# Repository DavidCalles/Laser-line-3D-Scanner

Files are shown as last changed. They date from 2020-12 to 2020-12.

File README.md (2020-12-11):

# Laser-Line 3D Scanner
By David Calles.

# Description
This repository contains all the code, models, image sets, and diagrams for an implementation of a 3D scanner at a prototype level. Consisting of a code for the computer-end and a code for the raspberrypi-end. 
Each step must be performed individually by running each code with its corresponding pre-requisites and using the ourputs of the block before.

# Requirements
The package requirements to run the algorithms are listed in the requirements.txt file. And can be install using:

    pip3 install -r requirements.txt
 or, if one has Anaconda installed:
 
    conda install --file requirements.txt

# Software blocks diagram
The following image illustrates the main stages of the software in the repository. 
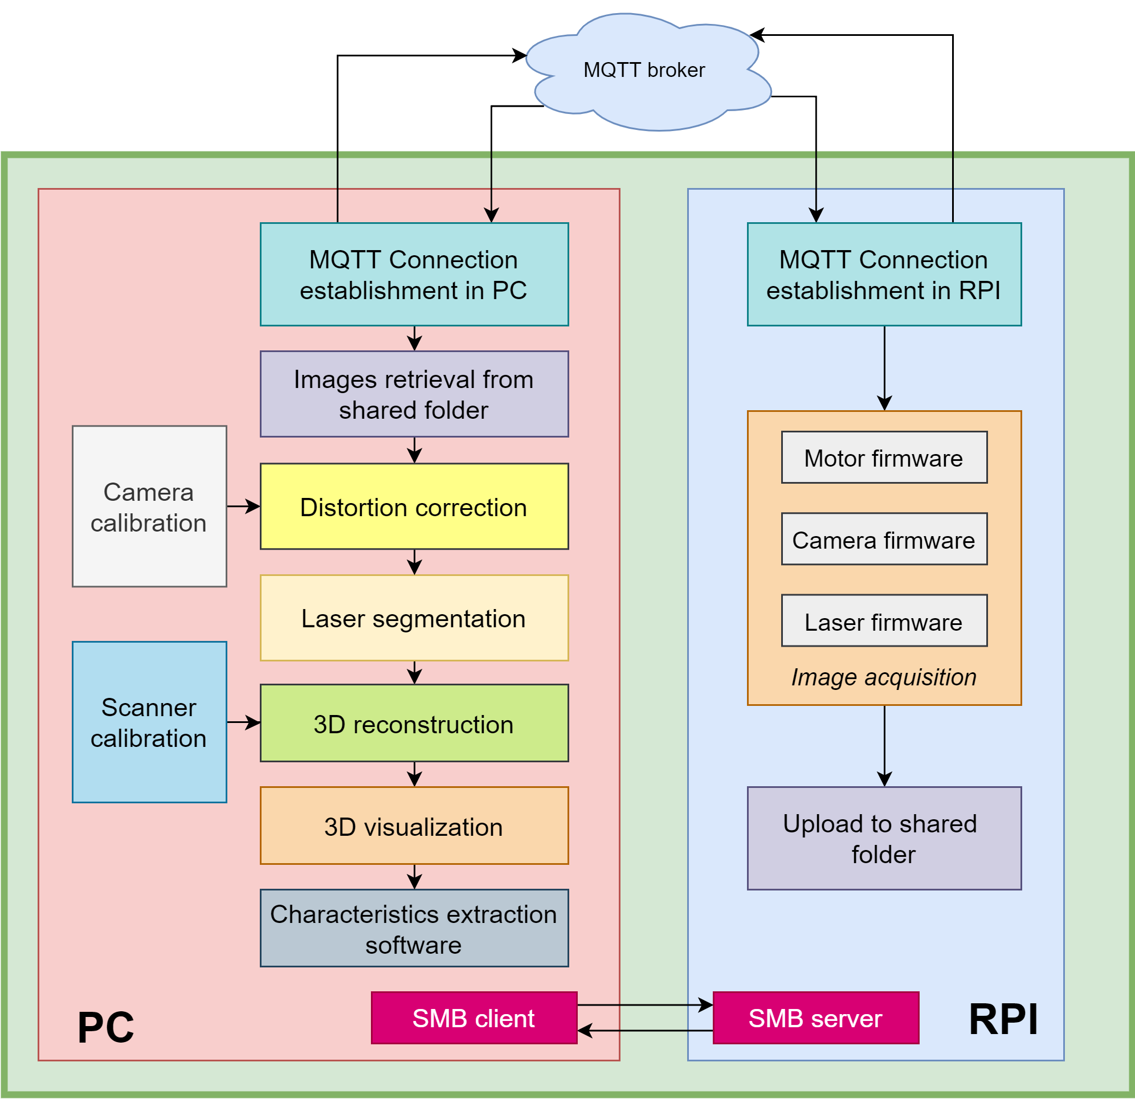
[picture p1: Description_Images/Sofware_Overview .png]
Blocks_Diagram


To get more information on each block as well as the fundamentals and theory of each algorithm, you are encourage to read the book located in the "Official_Documents" folder. In this document, the results using this scanner as well as a comparison with a time-of-flight sensor, and a plenoptic camera results is exposed.

# Files and folders
## Image sets
All the image sets needed to perform the different calibrations are included:

 - Camera calibration image set (100 images)
 - Scanner calibration image set (212 images = 106 image pairs)
 - Center calibration image set (4 images)

The same way, two different image sets for reconstructing its point clouds are included:

 - Volleyball ball (1500 images = 750 image pairs) 
 - Chili plant (1500 images = 750 image pairs)

## Sample point clouds

Two ascci XYZ files of the reconstructed point clouds are also shared in the "Sample point clouds" folder.

## 3D-print models
All the models for printing the car, the platform segments, the motor adapters, and the of the scanner are shared as STL files. More information can be found in the final book pdf file. 

## PCB files
All the gerber and drill files of the PCB for circuits for the motor driver and adapter to the RaspberryPi 4B are shared. More information can be found in the final book pdf file.

## Raspberry Pi-end codes
The codes that must run on the raspberry pi are shared in the "RaspberryPi_Codes" folder, including:

 - Test code for motor.
 - MQTT communication with image acquisition.
 - Acquisition of calibration images.

## Computer-end codes
In the root folder of the repository are the computer-end codes of the project, including.

 - MQTT communication with raspberry-pi.
 - Camera calibration.
 - Scanner calibration.
 - Center calibration.
 - Point cloud reconstruction.
 - Features extraction.

## Calibration files
Some default calibration files are also shared in the root folder of the repository, including:

 - Camera calibration result file.
 - Scanner calibration result file.

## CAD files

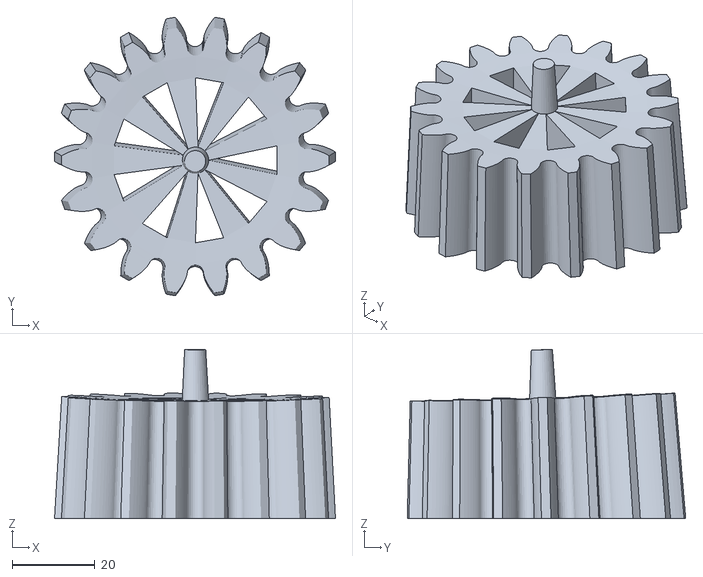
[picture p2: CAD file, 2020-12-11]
Models_3D_PRINT/Gear_NoMotor_Cap2.stl
68.1 x 67.4 x 41.0

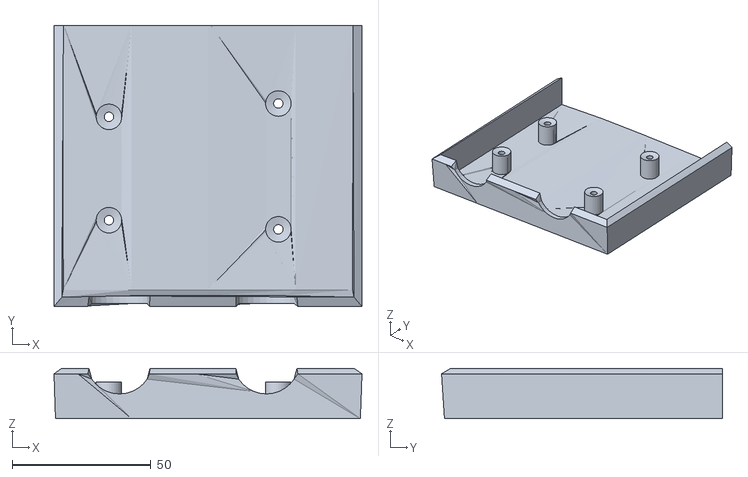
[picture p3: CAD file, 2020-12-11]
Models_3D_PRINT/Car_Cap1_Half2.stl
111.1 x 101.3 x 18.2

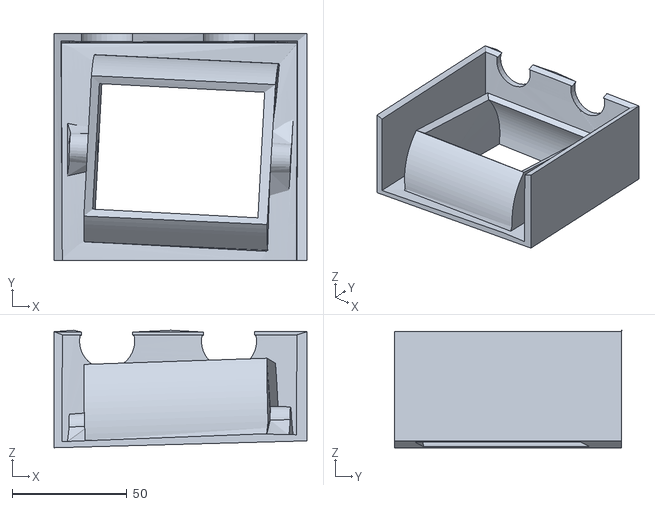
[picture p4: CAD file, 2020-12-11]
Models_3D_PRINT/Car_Cap2_Half1.stl
110.0 x 98.8 x 51.1

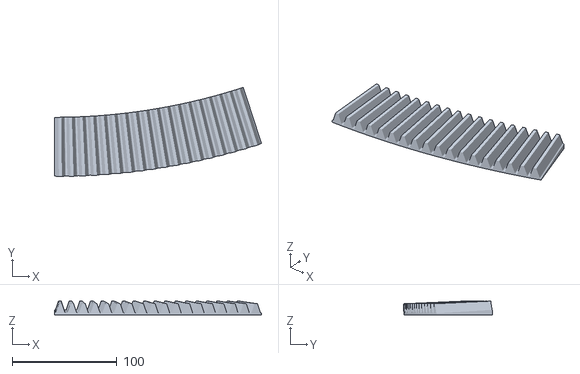
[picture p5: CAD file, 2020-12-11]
Models_3D_PRINT/Toothed_Segment_20Needed.stl
197.5 x 85.1 x 13.0

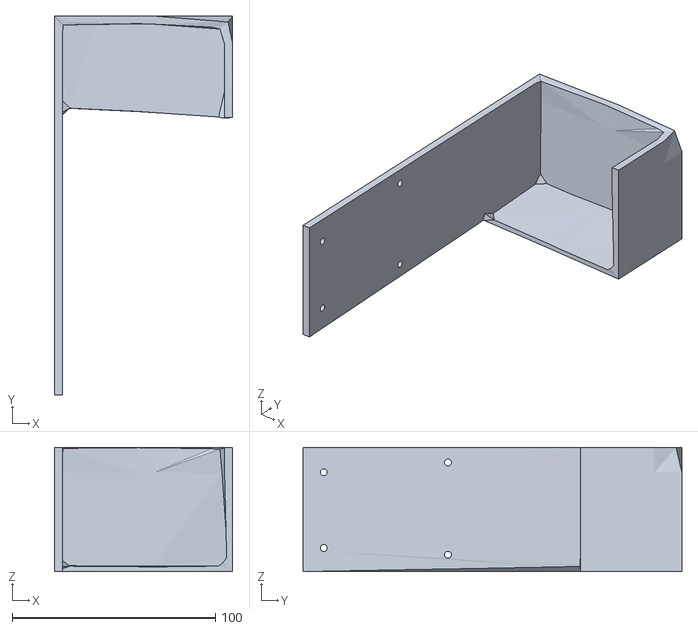
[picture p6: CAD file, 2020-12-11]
Models_3D_PRINT/Support_Motor.stl
87.8 x 186.5 x 61.1

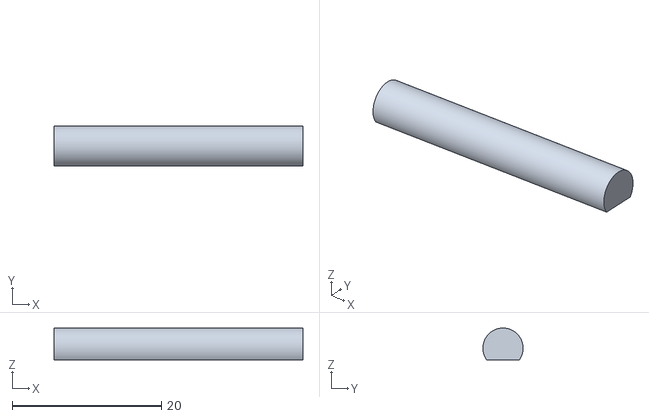
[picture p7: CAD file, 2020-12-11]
Models_3D_PRINT/Motor_Adapter_InGear.stl
33.4 x 5.40 x 4.28

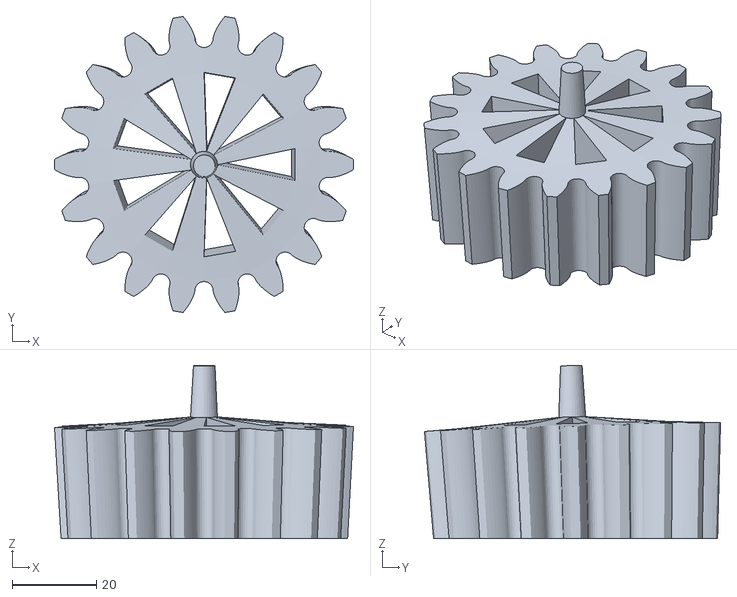
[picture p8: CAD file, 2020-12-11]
Models_3D_PRINT/Gear_NoMotor_Cap1.stl
71.0 x 70.3 x 41.2

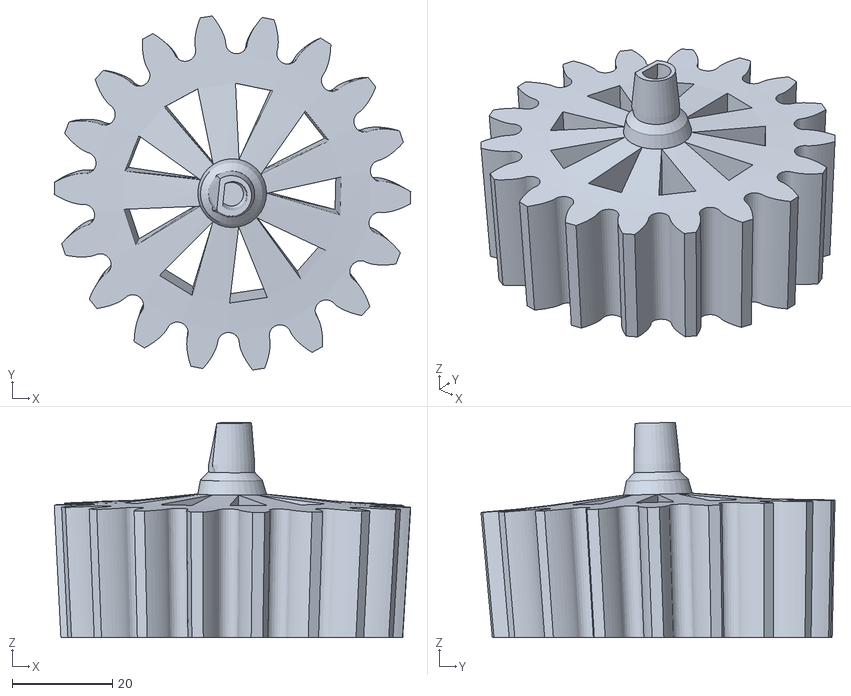
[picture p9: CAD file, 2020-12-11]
Models_3D_PRINT/Gear_Motor_Cap1.stl
71.0 x 70.5 x 42.8

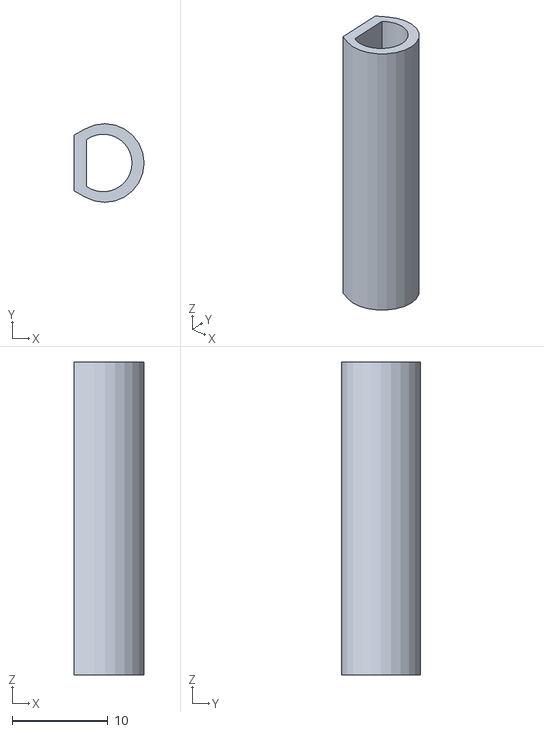
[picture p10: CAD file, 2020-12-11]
Models_3D_PRINT/Motor_Adapter_InMotor.stl
7.34 x 8.23 x 32.7

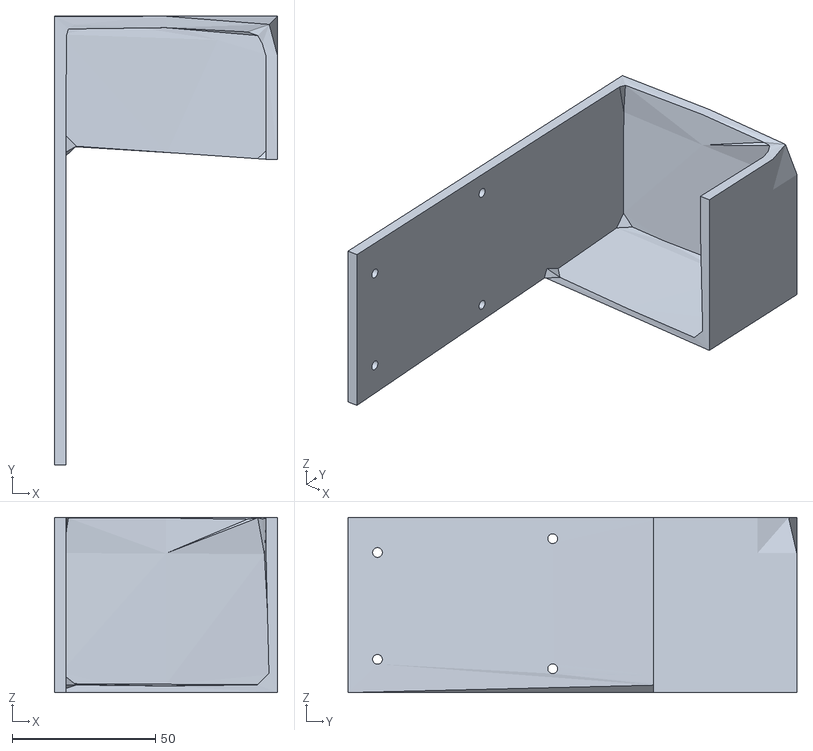
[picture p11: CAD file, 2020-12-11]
Models_3D_PRINT/Support_Counterweight.stl
77.8 x 156.5 x 61.1

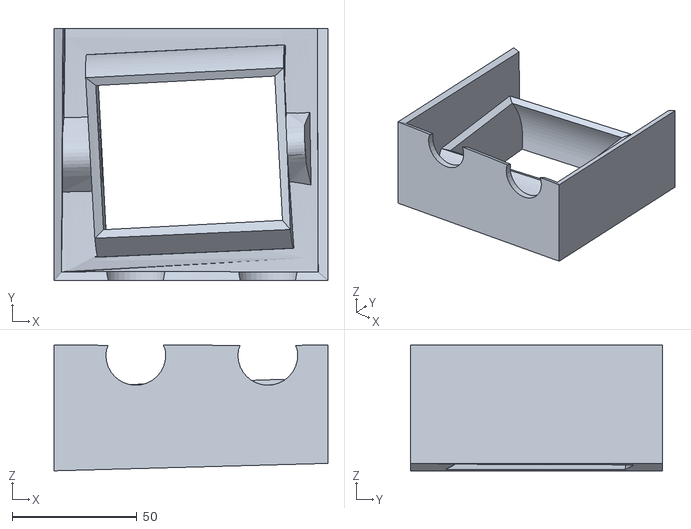
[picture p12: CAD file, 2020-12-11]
Models_3D_PRINT/Car_Cap2_Half2.stl
110.0 x 101.2 x 50.5

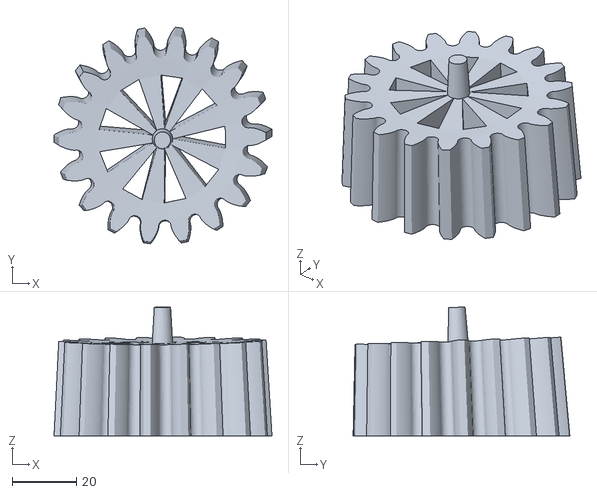
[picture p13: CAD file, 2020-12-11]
Models_3D_PRINT/Gear_Motor_Cap2.stl
68.1 x 67.7 x 40.3

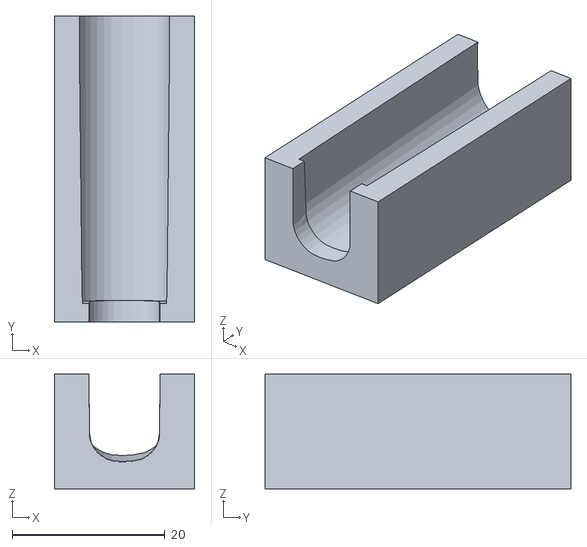
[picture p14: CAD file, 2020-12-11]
Models_3D_PRINT/Laser_Holder.stl
18.3 x 40.0 x 15.0

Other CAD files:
Models_3D_PRINT/Car_Cap1_Half1.stl

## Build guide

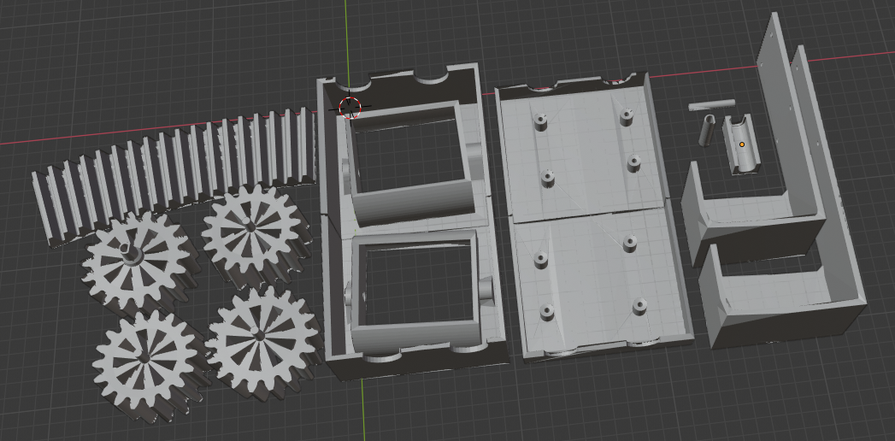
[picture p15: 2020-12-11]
Models_3D_PRINT/Screeshot_3DPrints.PNG

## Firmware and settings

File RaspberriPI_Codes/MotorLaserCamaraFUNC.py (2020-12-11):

"""
##############################################################################
#
#   MODULE DESCRIPTION:
#        This module contains the algorithms to take image pairs with the 
#           raspberry pi board. Using an usb webcam, a laser-line module and
#           a motor driver connected to the GPIO of the board.
#
#   PRE-REQUISITES: 
#           Have the hardware wired properly.     
#    
#    ACTION:                             DATE:           NAME:
#        First implementation and tests      10/Aug/2020      David Calles
#        Code comments and last review       9/Dic/2020       David Calles           
#
##############################################################################
"""

#----------------------------------------------------------------------------#
#------------------------ REQUIRED EXTERNAL PACKAGES ------------------------#
#----------------------------------------------------------------------------#
import time
import RPi.GPIO as GPIO
import cv2

#----------------------------------------------------------------------------#
# ----------------------- MOTOR MOVEMENT SETTINGS ---------------------------#
#----------------------------------------------------------------------------#
dir_pin   = 11
step_pin  = 13
laser_pin = 3
cap = cv2.VideoCapture(0)
cap.set(cv2.CAP_PROP_FRAME_WIDTH, 1920)
cap.set(cv2.CAP_PROP_FRAME_HEIGHT, 1080)  

#----------------------------------------------------------------------------#
# ----------------------- FUNCTION DEFINITIONS ------------------------------#
#----------------------------------------------------------------------------# 

"""***************************************************************************   
# NAME: Clean_All
# DESCRIPTION:  Reset interfaces to original values
#               
# PARAMETERS:   None
#                              
# RETURNS:      None           
#               
#       ACTION:                         DATE:       NAME:
#       First implementation and tests  19/Aug/2020      David Calles
#       Review and documentation        9/Dec/2020       David Calles
***************************************************************************"""
def Clean_All():
    GPIO.output(step_pin, 0)
    GPIO.output(dir_pin, 0)
    GPIO.output(laser_pin, 0)
    GPIO.cleanup()
    cap.release()
    cv2.destroyAllWindows()
    cv2.waitKey(1)

"""***************************************************************************   
# NAME: Move_Motor
# DESCRIPTION:  Move motor a single time.
#               
# PARAMETERS:   steps: Amount of 1.8° steps to perform.
#               direction: Direction of movement. Clockwise-counterwise.
#               dir_pin: Pin to output of the direction signal
#               step_pin: Pin to output of the step signal.
#               one_step: Duration seconds of a single step.
#                              
# RETURNS:      None           
#               
#       ACTION:                         DATE:       NAME:
#       First implementation and tests  19/Aug/2020      David Calles
#       Review and documentation        9/Dec/2020       David Calles
***************************************************************************""" 
def Move_Motor(steps, direction, dir_pin, step_pin, one_step):
    GPIO.output(dir_pin, direction) # 0 (clockwise)
    for i in range(steps):
        GPIO.output(step_pin, 1)
        time.sleep(one_step)
        GPIO.output(step_pin, 0)
        time.sleep(one_step)
    return 1

"""***************************************************************************   
# NAME: Take_Images_wMotor
# DESCRIPTION:  Take a certain amount of images. A motor movement is performed
#               between image pairs. Each image pair consists of a lasered
#               and a laser-less image.
#               
# PARAMETERS:   path: Directory where images should be saved.
#               num: Amount of image pairs to take.
#               save: Enable image save.
#                              
# RETURNS:      None.            
#               
#       ACTION:                         DATE:       NAME:
#       First implementation and tests  19/Aug/2020      David Calles
#       Review and documentation        9/Dec/2020       David Calles
***************************************************************************"""
def Take_Images_wMotor(path="/home/pi/Documents/SharedImages/Scans/Scan_0/",
                       num=10, save=True):
    GPIO.setmode(GPIO.BOARD)
    GPIO.setwarnings(False)
    SAVE = save
    save_path = path

    one_step = 0.004 #>5ms feels smooth (speed)
    steps_num = 10 # 200 = 1 turn
    SLEEPTIME = 1 #(s) time from turning laser ON to taking image
    CLOCKWISE = 0
    COUNTERWISE = 1
    MOVING_MOTOR = False

    # RASPI GPIO outputs setup
    GPIO.setup(dir_pin, GPIO.OUT)
    GPIO.setup(step_pin, GPIO.OUT)
    GPIO.setup (laser_pin, GPIO.OUT)

    iteration = 0
    trash_iter = 0
    max_iter = num
    try:
        while(iteration < max_iter):
            print("Iteration ", iteration)
            # LASER OUTPUT        
            GPIO.output(laser_pin, 1)
            time.sleep(SLEEPTIME)
            ret1, frame1 = cap.read()

            GPIO.output(laser_pin, 0)
            time.sleep(SLEEPTIME)
            ret2, frame2 = cap.read()
            # First images are discarded and motor is not moved.
            if trash_iter > 8:
                MOVING_MOTOR = True
            # COUNT images to be taken.   
            if MOVING_MOTOR:
                if iteration < max_iter:
                    if SAVE:
                        path1 = save_path + "/Image_{}.png".format(
                            iteration*2)
                        path2 = save_path + "/Image_{}.png".format(
                            (iteration*2)+1)
                        cv2.imwrite(path1, frame1)
                        cv2.imwrite(path2, frame2)
                    Move_Motor(steps_num, CLOCKWISE, dir_pin,
                               step_pin, one_step)
                    time.sleep(1)
                iteration += 1
            trash_iter +=1
        Clean_All()
    # EXIT securely by using Ctrl-C        
    except KeyboardInterrupt:
        print("System stoped manually!")
        Clean_All()
    except TypeError:
        print("Please connect usb camera!")
        Clean_All()

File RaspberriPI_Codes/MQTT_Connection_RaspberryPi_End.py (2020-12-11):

#! /usr/bin/python3

"""
##############################################################################
#
#   MODULE DESCRIPTION:
#       This module has the required code to stablish an MQTT connection 
#       between the raspberry-pi and the main processing unit (a desktop 
#       computer or laptop) FROM THE RASPBERRY PI END.
#       An MQTT message exchange is performed and the amount of images to be
#       taken as well as the directory to save them. 
#       Between image pairs, the motor is moved and the laser is turned ON and
#       OFF.
#        
#   USAGE:
#        The atributes of the MQTT are specified with variables as following 
#        by default:
#            
#            my_host = "broker.hivemq.com"   #Broker
#            my_port = 1883                  #Port
#            my_topic = "Scanner3D_David"    #Topic
#            my_qos = 2                      #Quality of service (0,1,2)
#        
#        However, can (and should) be changed to the ones desired both in the 
#        COMPUTER END and EMBEDDED SYSTEM END codes.
#        
#       By default, retrieved images are saved locally in the defined folder.
#        
#        NOTES:  Please take into account that for this code to work properly
#                a shared folder must be prepared in advance between the 
#                embedded system and the computer.
#                Also, the EMBEDDED SYSTEM END  code must be run before the 
#                COMPUTER END code.
#    
#    ACTION:                             DATE:           NAME:
#        First implementation and tests      2/Nov/2020      David Calles
#        Code comments and last review       9/Dic/2020      David Calles                
#
##############################################################################
"""

#----------------------------------------------------------------------------#
#------------------------ REQUIRED EXTERNAL PACKAGES ------------------------#
#----------------------------------------------------------------------------#
import paho.mqtt.client as MQTT
import os

#----------------------------------------------------------------------------#
# ----------------------- REQUIRED OWN FUNCTIONS-----------------------------#
#----------------------------------------------------------------------------#
from MotorLaserCamaraFUNC import Take_Images_wMotor

#----------------------------------------------------------------------------#
# ----------------------- MQTT HANDSHAKE STRUCTURE --------------------------#
#----------------------------------------------------------------------------#
# --------------- INITIATE HAND-SHAKE (PC-RPI) WITH MQTT ---------------------
# PC  --> "START"
# RPI --> "ACK1"
# PC  --> "FOLDER_"+scan_name
# RPI --> "ACK2_"+scan_name
# PC  --> "INITIATE_"+image_pairs
# RPI --> "ACK3_" +image_pairs
# DISCONNECT()

#----------------------------------------------------------------------------#
# -------------- CONNECTION AND FEATURE ENABLING VARIABLES ------------------#
#----------------------------------------------------------------------------#
my_host = "broker.hivemq.com"
my_port = 1883
my_topic = "Scanner3D_David"
my_qos = 2
scan_name = '0'
image_pairs = '0'

payload1_PC = "START"
payload2_PCh = "FOLDER_"
payload3_PCh = "INITIATE_"

payload1_RPI = "ACK1"
payload2_RPIh = "ACK2_"
payload3_RPIh = "ACK3_" 

#----------------------------------------------------------------------------#
#-------------------------MQTT FUNCTION DEFINITIONS -------------------------#
#----------------------------------------------------------------------------#
# CALLBACK FUNCTION FOR MQTT DISCONNECTION TO BROKER 
def on_disconnect(client, userdata, rc):
    if rc != 0:
        print("Unexpected disconnection.")
    else:
        print("Client disconnected. ")
        
# CALLBACK FUNCTION FOR MQTT CONNECTION TO BROKER 
def on_connect(client, userdata, flags, rc):
    print('connected (%s)' % client._client_id)
    client.subscribe(topic=my_topic, qos=my_qos)
    client.publish(my_topic, payload="RPI Suscribed", qos=my_qos)

# CALLBACK FUNCTION FOR MQTT  RECEIVED MESSAGE 
    # EVALUATE received messages
def on_message(client, userdata, message):
    msg = message.payload.decode()
    print("MESSAGE: ", msg)
    if(msg == payload1_PC):
        client.publish(my_topic, payload=payload1_RPI, qos=my_qos)
    if(msg[0:7] == payload2_PCh[0:7]):
        global scan_name
        scan_name = msg[7:]
        client.publish(my_topic, payload=(payload2_RPIh+scan_name),
                       qos=my_qos)
    if(msg[0:9] == payload3_PCh[0:9]):
        global image_pairs
        image_pairs = msg[9:]
        client.publish(my_topic, payload=(payload3_RPIh+image_pairs),
                       qos=my_qos)
        print ("CONNECTION WITH PC STABLISHED SUCCESFULLY!")
        client.disconnect()      

# HANDSHAKE FUNCTION
def MQTT_Handshake_RPI():
    client = MQTT.Client(client_id='My_rpi_DavidC')#my_clientid
    client.on_connect = on_connect
    client.on_message = on_message
    client.on_disconnect = on_disconnect
    client.connect(host=my_host, port=my_port)
    client.loop_forever()
try:
    # INITIATE handshake
    MQTT_Handshake_RPI()
    print ("Folder name: ", scan_name)
    print ("Image pairs amount: ", image_pairs)
    image_pairs = int(image_pairs)
    #------------ CREATE DIRECTORY FOR SCAN IMAGES -------
    path = "/home/pi/Documents/SharedImages/Scans/"+scan_name
    try:
        os.mkdir(path)
    except OSError:
        print ("Creation of the directory %s failed" % path)
    else:
        print ("Successfully created the directory %s " % path)
        # TAKE images moving motor.
        Take_Images_wMotor(path, image_pairs, save=True)

except:
    print("ERROR: PLEASE CHECK CONNECTION AND REBOOT DEVICE!")

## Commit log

2020-12-11 ADD Computer-end code
    Camera calibration, Scanner-calibration, Center-calibration, utility algorithms, MQTT communication on computer end, point cloud reconstruction, and feature extraction code is added.
2020-12-11 ADD 3D models of scanner
    Gears, car, motor adapters, toothed segment, supports, and a laser holder in STL format are added
    [Car_Cap1_Half1.stl, Car_Cap1_Half2.stl, Car_Cap2_Half1.stl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]
2020-12-11 ADD camera calibration image set
2020-12-11 ADD RaspberryPi-End code
    MQTT communication for raspberry-pi end, code for testing motor, and code for manually acquiring calibration images are added.
2020-12-11 ADD center calibration image set
2020-12-11 ADD sample point clouds
    A volleyball ball and a chili plant point clouds with rgb data are added.
2020-12-11 ADD Scanner calibration image set
2020-12-11 ADD default calibration files
    The used calibration files for the camera and the scanner are added.
2020-12-11 ADD PCB files
    [PCB_Motor-B_Cu.gbr, PCB_Motor-B_Mask.gbr, PCB_Motor-Edge_Cuts.gbr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]
